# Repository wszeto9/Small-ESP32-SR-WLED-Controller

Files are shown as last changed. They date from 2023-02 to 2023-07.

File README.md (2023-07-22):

# Small ESP32 SR-WLED Controller

A small LED controller that runs WLED-Sound Reactive. Supports 5-24V analog and addressible lights.

[Interactive BOM](https://htmlpreview.github.io/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)

<h2> Features:</h2>
<ul>
<li>4 Analog Channels (Up to 3A each) for analog RGB and RGBW LED strips</li>
<li>2 Addressible Channels, level shifted to 5V to support single data line and dual data line addressible LED strips.
<li>Variable Input voltage from 5-24V (Input voltage must match the LED strip voltage)
<li>Controlled with an ESP8266 running WLED and connected over Wi-Fi</li>
<li>Panelized in a 2x2 panel of 50x50mm for minimal fabrication costs at JLCPCB</li>
<li>BOM cost is kept low at around $6 per board
</ul>
<h2>Pinout</h2>

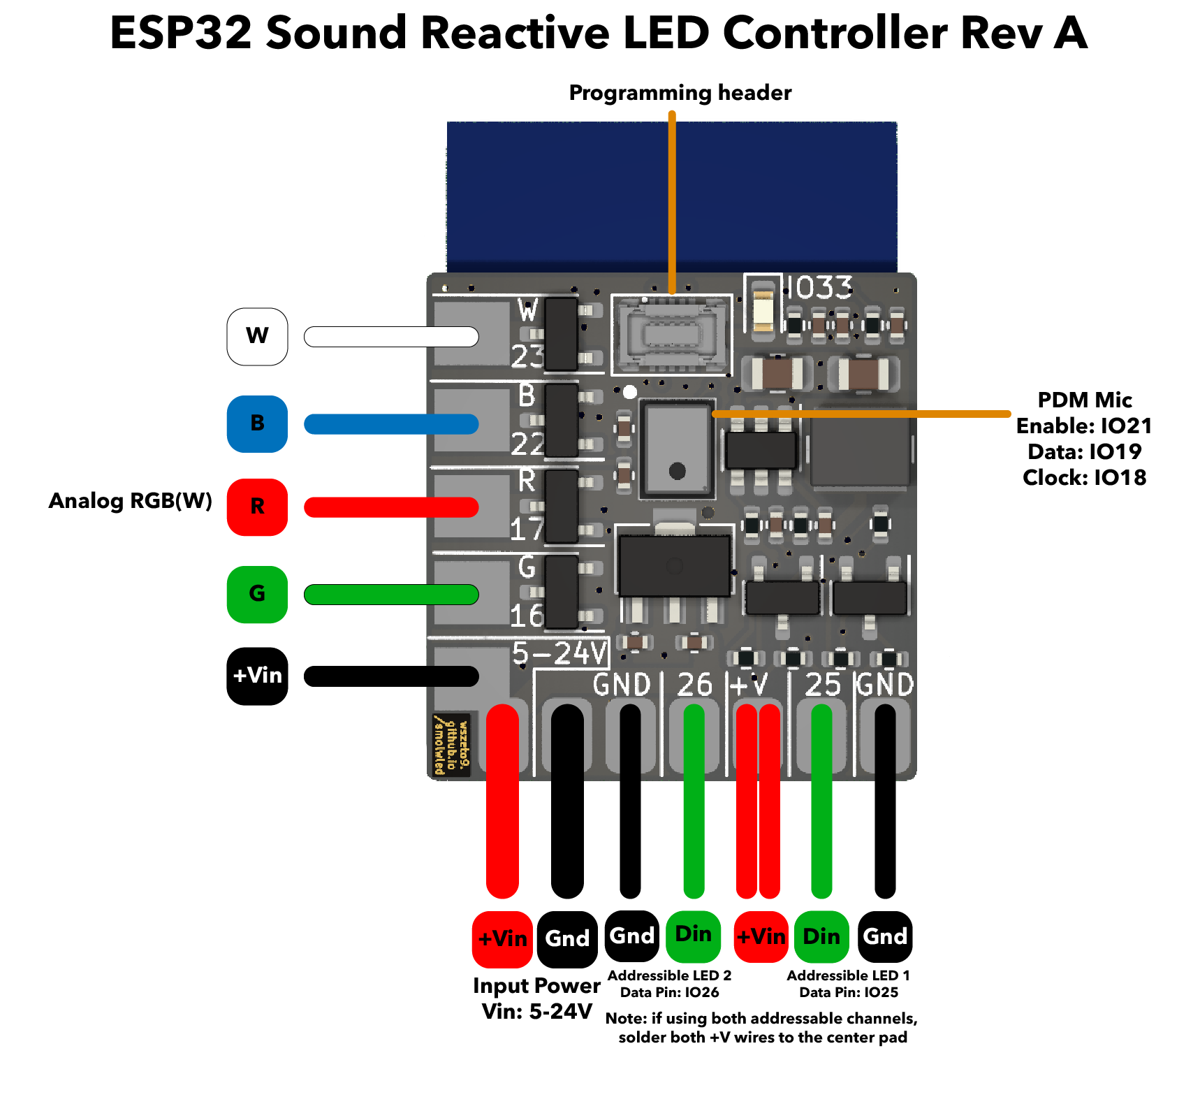
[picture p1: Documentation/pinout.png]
Pinout

<h2> Bring-up and Usage </h2>

- All front components should be soldered by JLCPCB.
- Flip the board and solder the ESP32 WROOM chip.
- Attach the programming device onto the mezzamine connector on the top front of the board
- Program the ESP32 with WLED
- Unplug the programming header
- Solder on lights and a power lead
- Connect to the ESP's Wi-Fi network and turn on the lights!

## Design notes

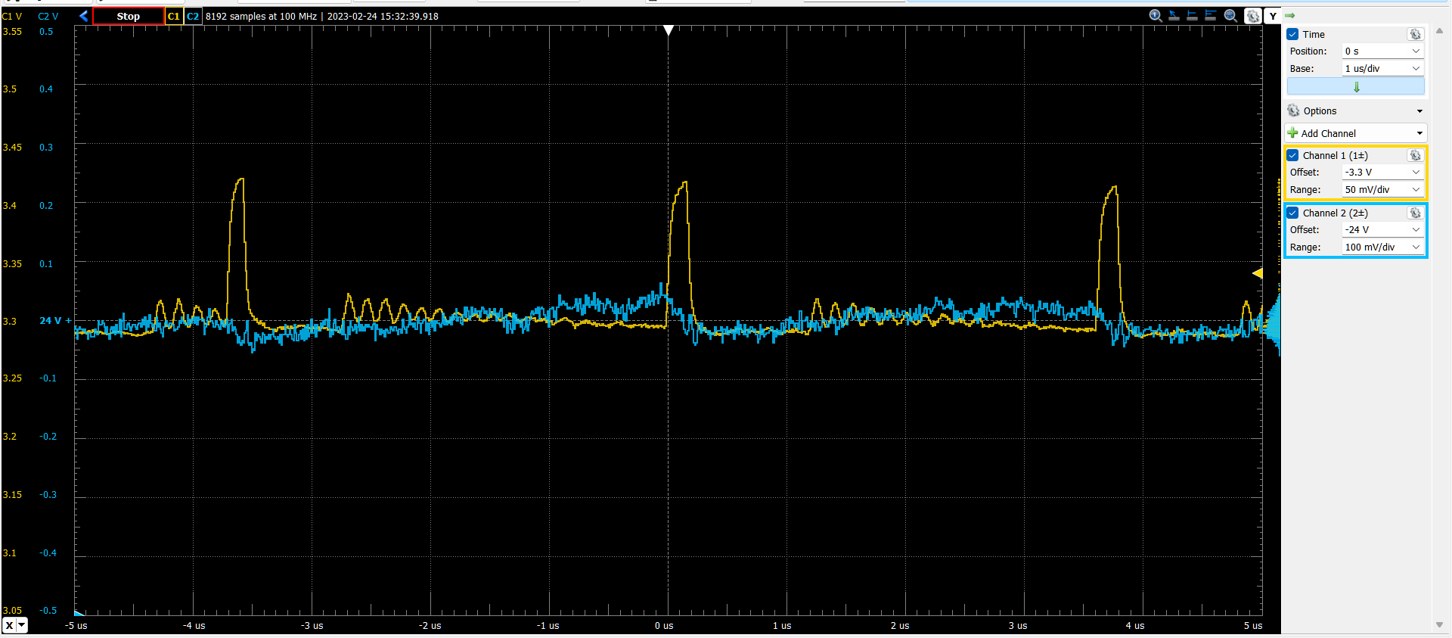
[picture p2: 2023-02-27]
Documentation/3V3ripple_24Vin.png

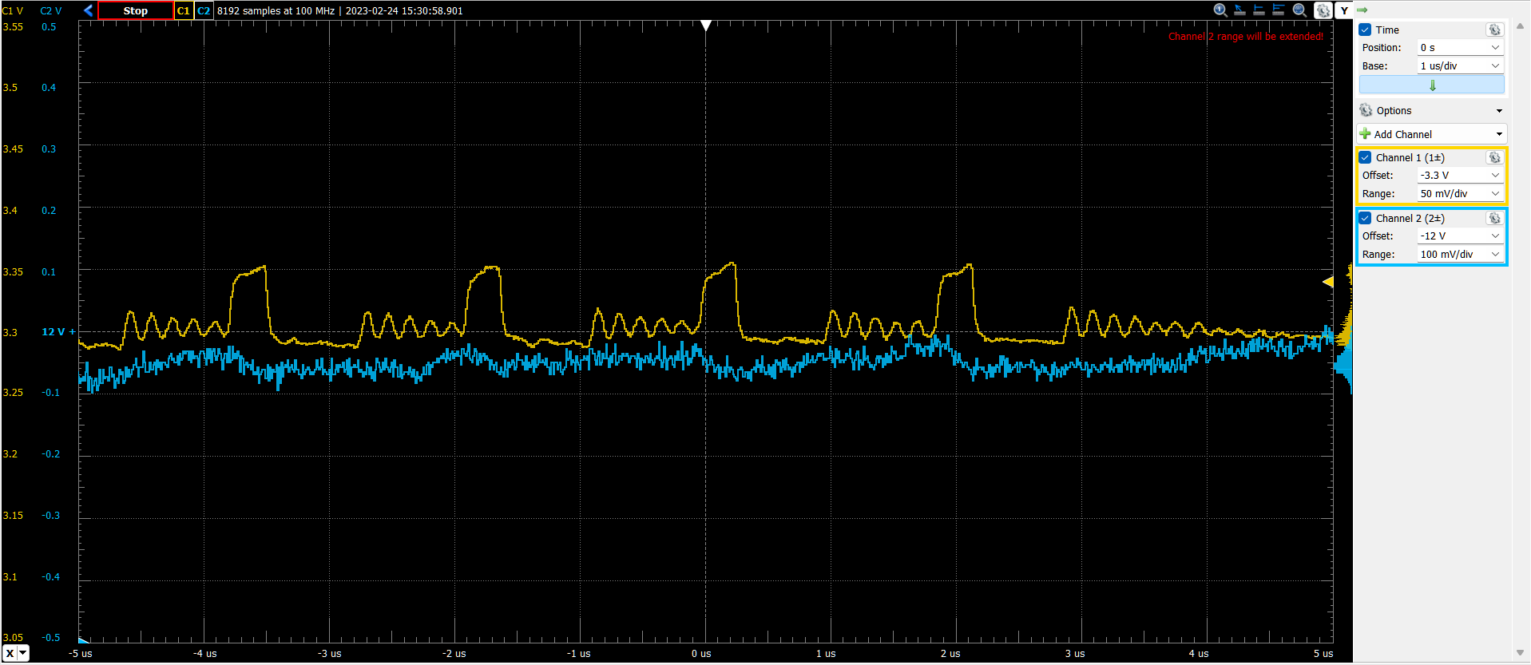
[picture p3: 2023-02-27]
Documentation/3V3ripple_12Vin.png

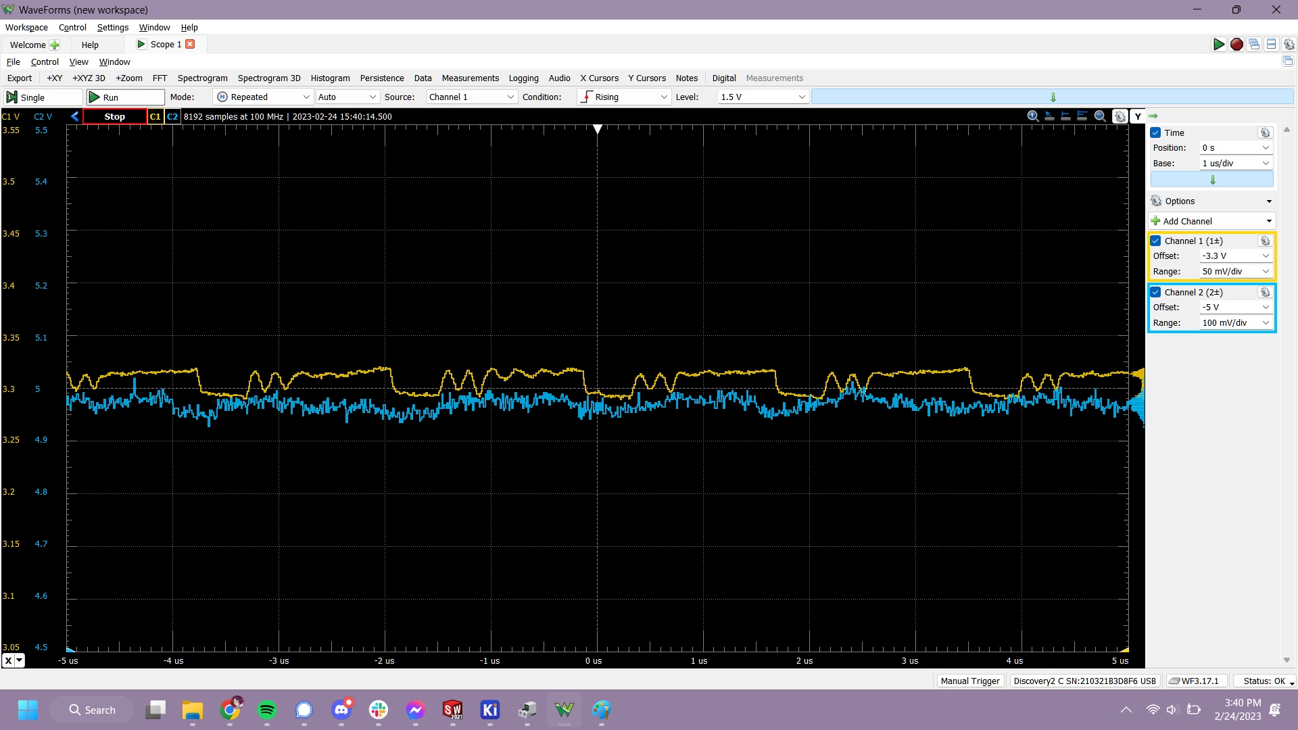
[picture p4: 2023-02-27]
Documentation/3V3ripple_5Vin.png

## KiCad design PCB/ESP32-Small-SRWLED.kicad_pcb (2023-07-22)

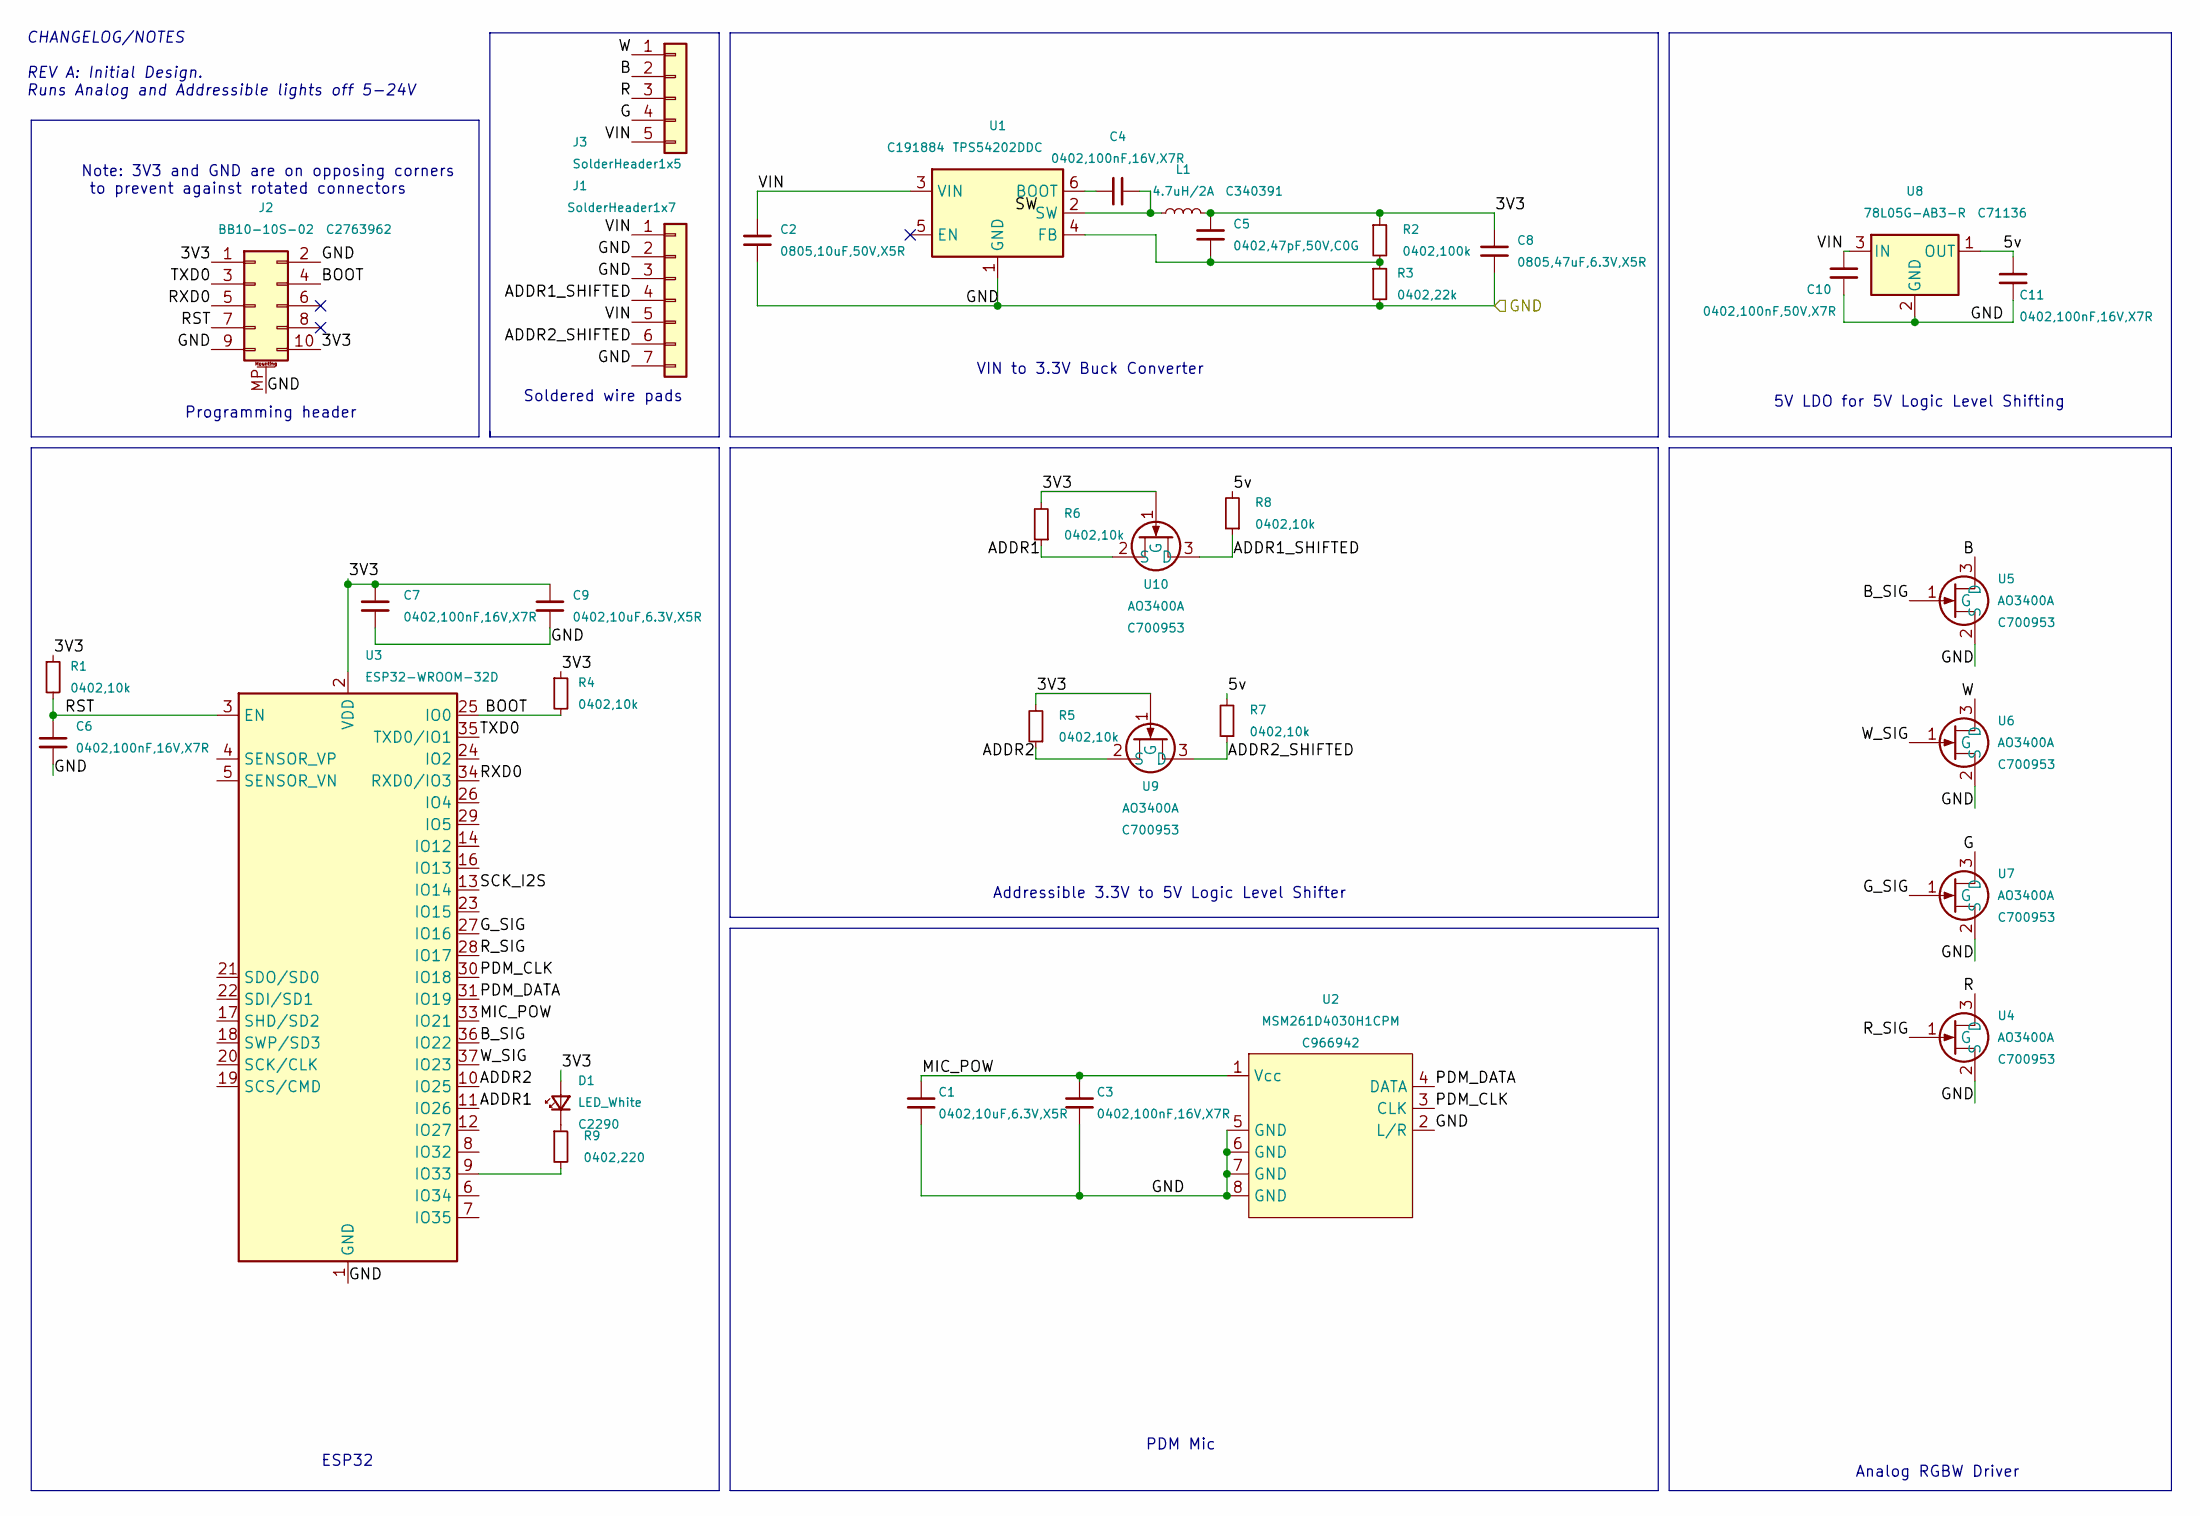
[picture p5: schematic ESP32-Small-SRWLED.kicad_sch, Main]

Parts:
C1, C9: 0402,10uF,6.3V,X5R; C_0402_1005Metric; MFGPN CL05A106MQ5NUNC; LCSC C15525
C2: 0805,10uF,50V,X5R; C_0805_2012Metric; MFGPN GRM21BR61H106KE43L; LCSC C440198
C3, C4, C6, C7, C11: 0402,100nF,16V,X7R; C_0402_1005Metric; MFGPN CL05B104KO5NNNC; LCSC C1525
C5: 0402,47pF,50V,C0G; C_0402_1005Metric; MFGPN 0402CG470J500NT; LCSC C1567
C8: 0805,47uF,6.3V,X5R; C_0805_2012Metric; MFGPN CL21A476MQYNNNE; LCSC C16780
C10: 0402,100nF,50V,X7R; C_0402_1005Metric; MFGPN CL05B104KB54PNC; LCSC C307331
D1: LED_White; LED_0603_1608Metric; LCSC C2290
J1: SolderHeader1x7; 1x7 wire solder pad
J2: BB10-10S-02; YXT-BB10-10S-02; LCSC C2763962
J3: SolderHeader1x5; 1x5 solder pad
L1: 4.7uH/2A; L_Wuerth_MAPI-4030; MFGPN YNR4030-4R7M; LCSC C340391
R1, R4, R5, R6, R7, R8: 0402,10k; R_0402_1005Metric; MFGPN 0402WGF1002TCE; LCSC C25744
R2: 0402,100k; R_0402_1005Metric; MFGPN 0402WGF1003TCE; LCSC C25741
R3: 0402,22k; R_0402_1005Metric; MFGPN 0402WGF2202TCE; LCSC C25768
R9: 0402,220; R_0402_1005Metric; MFGPN 0402WGF2200TCE; LCSC C25091
U1: TPS54202DDC; SOT-23-6; MFGPN TPS54202DDCR; LCSC C191884
U2: MSM261D4030H1CPM; LCSC C966942
U3: ESP32-WROOM-32D; ESP32-WROOM-32; LCSC C473005
U4, U5, U6, U7, U9, U10: AO3400A; SOT-23; LCSC C700953
U8: 78L05G-AB3-R; SOT-89-3; LCSC C71136

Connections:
/3V3: C5.1, C7.1, C8.1, C9.1, D1.2 (A), J2.1, J2.10, L1.2, R1.1, R2.1, R4.1, R5.2, R6.2, U3.2 (VDD), U9.1 (G), U10.1 (G)
/5v: C11.1, R7.2, R8.2, U8.1 (OUT)
/ADDR1: R6.1, U3.11 (IO26), U10.2 (S)
/ADDR1_SHIFTED: J1.4, R8.1, U10.3 (D)
/ADDR2: R5.1, U3.10 (IO25), U9.2 (S)
/ADDR2_SHIFTED: J1.6, R7.1, U9.3 (D)
/B: J3.2, U5.3 (D)
/BOOT: J2.4, R4.2, U3.25 (IO0)
/B_SIG: U3.36 (IO22), U5.1 (G)
/G: J3.4, U7.3 (D)
/GND: C1.2, C2.2, C3.2, C6.2, C7.2, C8.2, C9.2, C10.2, C11.2, J1.2, J1.3, J1.7, J2.2, J2.9, J2.MP (MountPin), R3.2, U1.1 (GND), U2.2 (L/R), U2.5 (GND), U2.6 (GND), U2.7 (GND), U2.8 (GND), U3.1 (GND), U3.15 (GND), U3.38 (GND), U3.39 (GND), U4.2 (S), U5.2 (S), U6.2 (S), U7.2 (S), U8.2 (GND)
/G_SIG: U3.27 (IO16), U7.1 (G)
/MIC_POW: C1.1, C3.1, U2.1 (Vcc), U3.33 (IO21)
/PDM_CLK: U2.3 (CLK), U3.30 (IO18)
/PDM_DATA: U2.4 (DATA), U3.31 (IO19)
/R: J3.3, U4.3 (D)
/RST: C6.1, J2.7, R1.2, U3.3 (EN)
/RXD0: J2.5, U3.34 (RXD0/IO3)
/R_SIG: U3.28 (IO17), U4.1 (G)
/SCK_I2S: U3.13 (IO14)
/TXD0: J2.3, U3.35 (TXD0/IO1)
/VIN: C2.1, C10.1, J1.1, J1.5, J3.5, U1.3 (VIN), U8.3 (IN)
/W: J3.1, U6.3 (D)
/W_SIG: U3.37 (IO23), U6.1 (G)
unnamed: C4.1, U1.6 (BOOT)
unnamed: C4.2, L1.1, U1.2 (SW)
unnamed: C5.2, R2.2, R3.1, U1.4 (FB)
unnamed: D1.1 (K), R9.1
unnamed: R9.2, U3.9 (IO33)

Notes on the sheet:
5V LDO for 5V Logic Level Shifting
VIN to 3.3V Buck Converter
PDM Mic
Analog RGBW Driver
Programming header
Addressible 3.3V to 5V Logic Level Shifter
Soldered wire pads
ESP32
Note: 3V3 and GND are on opposing corners to prevent against rotated connectors
CHANGELOG/NOTES REV A: Initial Design. Runs Analog and Addressible lights off 5-24V

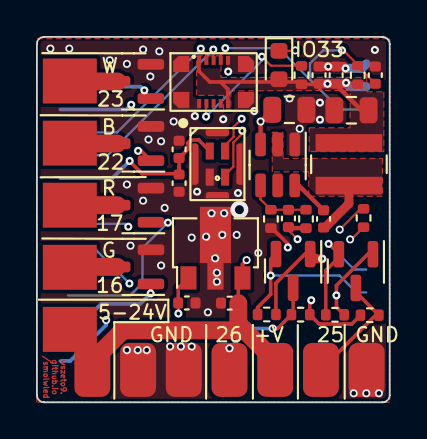
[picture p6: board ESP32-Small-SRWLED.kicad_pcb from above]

Board: 4 copper layers, 19.6 x 20.3 mm, 35 parts (1 on the bottom side), 28 nets.

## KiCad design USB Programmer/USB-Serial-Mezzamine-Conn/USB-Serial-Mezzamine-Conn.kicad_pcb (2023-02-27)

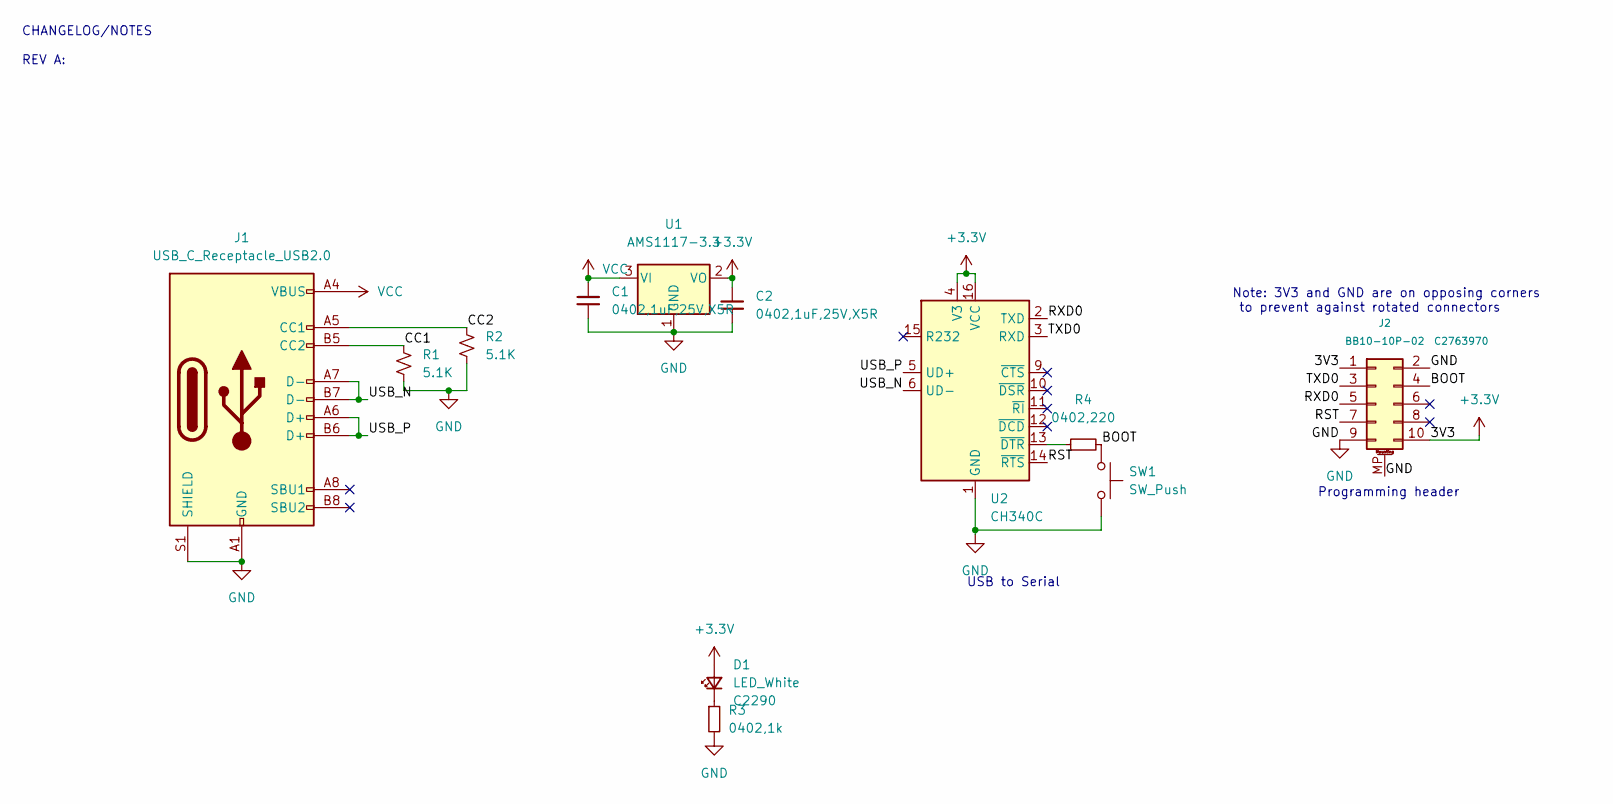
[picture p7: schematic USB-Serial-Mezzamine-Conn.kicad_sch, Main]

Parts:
C1, C2: 0402,1uF,25V,X5R; C_0402_1005Metric; MFGPN CL05A105KA5NQNC; LCSC C52923
D1: LED_White; LED_0603_1608Metric; LCSC C2290
J1: USB_C_Receptacle_USB2.0; USB_C_Receptacle_Palconn_UTC16-G; LCSC Part Number C165948
J2: BB10-10P-02; YXT-BB10-10P-02; LCSC C2763970
R1, R2: 5.1K; R_0402_1005Metric; LCSC Part Number C25905
R3: 0402,1k; R_0402_1005Metric; MFGPN 0402WGF1001TCE; LCSC C11702
R4: 0402,220; R_0402_1005Metric; MFGPN 0402WGF2200TCE; LCSC C25091
SW1: SW_Push; SW_PUSH_6mm
U1: AMS1117-3.3; SOT-223-3_TabPin2
U2: CH340C; SOIC-16_3.9x9.9mm_P1.27mm; LCSC Part Number C84681

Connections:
+3V3: C2.1, D1.2 (A), J2.1, J2.10, U1.2 (VO), U2.4 (V3), U2.16 (VCC)
/BOOT: J2.4, R4.2, SW1.1
/CC1: J1.B5 (CC2), R1.1
/CC2: J1.A5 (CC1), R2.1
/RST: J2.7, U2.14 (~RTS)
/RXD0: J2.5, U2.2 (TXD)
/TXD0: J2.3, U2.3 (RXD)
/USB_N: J1.A7 (D-), J1.B7 (D-), U2.6 (UD-)
/USB_P: J1.A6 (D+), J1.B6 (D+), U2.5 (UD+)
GND: C1.2, C2.2, J1.A1 (GND), J1.A12 (GND), J1.B1 (GND), J1.B12 (GND), J1.S1 (SHIELD), J2.2, J2.9, J2.MP (MountPin), R1.2, R2.2, R3.2, SW1.2, U1.1 (GND), U2.1 (GND)
unnamed: D1.1 (K), R3.1
unnamed: R4.1, U2.13 (~DTR)
VCC: C1.1, J1.A4 (VBUS), J1.A9 (VBUS), J1.B4 (VBUS), J1.B9 (VBUS), U1.3 (VI)

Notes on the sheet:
Programming header
Note: 3V3 and GND are on opposing corners to prevent against rotated connectors
USB to Serial
CHANGELOG/NOTES REV A:

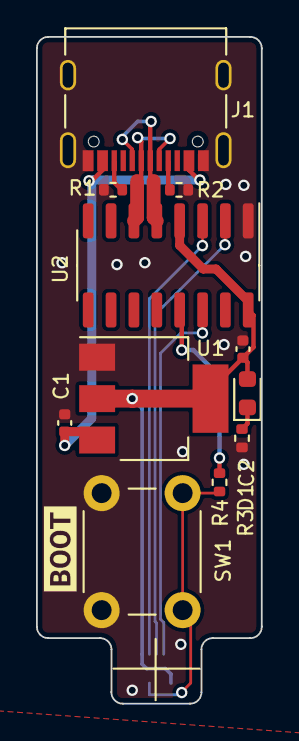
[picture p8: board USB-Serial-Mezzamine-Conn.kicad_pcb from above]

Board: 2 copper layers, 12.5 x 37.0 mm, 13 parts (1 on the bottom side), 13 nets.

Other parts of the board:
kibuzzard-63EDCBFB: G***; kibuzzard-63EDCBFB

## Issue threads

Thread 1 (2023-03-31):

Addressable LED Signal Integrity Issues

wszeto9, 2023-03-31:
While WS2812Bs were able to be controlled with the controller, the control signals have some SI issues. In summary, Rev A02 should include the following changes:
|Reference|Rev A01 Part|Rev A02 Part|
|--|--|--|
|U8|78L05G-AB3-R|AP2205-50YR-13‎|
|U9| AO3400A|BSS138|
|U10 | AO3400A|BSS138|
R7|10K 0402|1K 0402|
R9|10K 0402|1K 0402|

- The 5V Logic Voltage Regulator has a high dropout voltage of roughly 1.5V. This means, with a 5V VIN on the controller, the logic "5V" rail is only at 3.5V. A suggested replacement part for U8 is ‎AP2205-50YR-13‎. The part is pin-compatible and has a low dropout of ~ 100mV.
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
Figure 1:
Output Voltage (Vertical) vs Input Voltage (Horizontal) of U8 in Rev A01. Bottom left corner represents 0V on input and 0V on output. With 5V input, the output is approximately 3.8V. A 6.5V input voltage is required to sustain a 5V output voltage.
- The AO3400A has excess stray capacitance. It significantly loads the signal input such that the input signal takes roughly 100ns to rise to 3.3V. In addition, the AO3400A has a relatively high threshold voltage, leading to the mosfet taking too long to switch. The high-time of the output signal is at roughly 0.1us, which is not long enough to sufficiently control the WS2812B. It is recommended to use the BSS138 as a replacement for U9 and U10. The BSS138 is used in figure 3.
- 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
Figure 2: The affect of the AO3400A on the input signal. Logic Voltage (Yellow), microcontroller signal (Blue), Output signal(Red). The AO3400A significantly softens the signal. The point the mosfet turns off can be seen when the blue trace drops. The output signal does not reach a 3.5V threshold until 0.3us after the microcontroller signal first goes high.
- The pullups R7,R8 are not strong enough to pull up the output signal in a short period of time. They should be replaced with a 1K 0402 in order to drain parasitic capacitances quicker.
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
Figure 3: Effect of different pull-up values on switching transient. Logic Voltage (Yellow), microcontroller signal (blue), Output signal with 1K pullup (Red), Output signal with 10K pullup(Green). Since the weaker pullup takes longer to pull the signal high, the high-time of the signal is changed. U9 and U10 are using the BSS138.

For a logic 0 to be transmitted, the high pulse time must be between 0.25us and 0.55us. High pulse time is defined as the time at which a signal is above 3.5V (VIH) for the output signals, and is estimated to be 0.4us for the input.
|Signal| High pulse time|
|--|--|
|Input|0.4us|
|Output with 10K Pullup | 0.266us|
|Output with 1K Pullup | 0.378us|

The 1K pullup is significantly more resilient than the 10K pullup. With the 10K pullup, its high pulse time is very close to the acceptable  lower limit. The 1K pullup provides a much higher safety margin and is therefore a better choice as a pullup resistor value.

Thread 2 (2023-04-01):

Incorrect silkscreen

wszeto9, 2023-04-01:
The silkscreen is incorrect. ADDR1 and ADDR2 are swapped, and R and G should have a GPIO number that is one less than depicted on the silkscreen. The pinout should be as follows:

|Function | Pin Number|
|-|-|
|G | 16|
|R|17|
|B|22|
|W|23|
|ADDR1|26|
|ADDR2|25|

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
Figure 1: Silkcreen on Rev A
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

FIgure 2: Corrected Silkscreen

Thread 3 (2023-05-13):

nRST rising too quickly before BOOT is set correctly

wszeto9, 2023-05-13:
The nRST line on the ESP32 is switching to H approximately 1.5ms before the 3V3 voltage rail is stable, as shown in Fig. 1. This is undesirable, as the ESP32 may be unstable and go into an incorrect boot mode due to this. Some boards did not have a functional ESP32 due to the IC not turning on properly. To fix this issue, a 1uF capacitor is placed between nRST and GND (replacing the 100nF capacitor C6), resulting in the ESP32 reading nRST high approximately 8ms after 3V3 is stable, as shown in Fig 2.  The ESP32 was able to turn on properly after the fix.

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
**Figure 1:** A transient analysis of the circuit turning on. The blue curve is VIN, the cyan curve is 3V3, yellow is nRST, and purple is 0.75 * 3V3, which is the high threshold for the ESP32. The ESP32 gets an enable signal at -0.5ms, whereas 3V3 stabilizes at +1ms. The ESP32 is being told to turn on before the voltage rails are stable.

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
**Figure 2:** A transient analysis of the circuit turning on with a 1uF capacitor between nRST and GND. The blue curve is VIN, the yellow curve is 3V3, cyan is nRST, and purple is 0.75 * 3V3, which is the high threshold for the ESP32. Cursor AX shows when 3V3 is stable, and cursor BX shows when the ESP32 is enabled. The ESP32 is turned on approximately 8ms after the voltage rail is stabilized.

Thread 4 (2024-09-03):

Adding a capacitive touch sensor input

Arakistech, 2024-09-03:
Hi! Great work, your design is very nice.

I would like to add a capactive touch sensor input to it to switch the LEDs on/off with WLED. I would use the capacitive touch sensor through some milimeters of wood.  Do you know how can I do it?

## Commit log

2023-02-14 Routed components
    [ESP32-Small-SRWLED.kicad_pcb, ESP32-Small-SRWLED.kicad_sch]
2023-02-14 edited website link
    [ESP32-Small-SRWLED.kicad_pcb, ESP32-Small-SRWLED.kicad_sch]
2023-02-14 changed file dir
    [ESP32-Small-SRWLED.kicad_pcb, ESP32-Small-SRWLED.kicad_sch]
2023-02-27 sent to fab
    [ESP32-Small-SRWLED.kicad_pcb, ESP32-Small-SRWLED.kicad_sch, ESP32-Small-SRWLED_panelization.kicad_pcb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]
2023-02-27 Added scope shots of 3.3V ripple voltage
2023-04-01 moved bom and step to documentation
2023-07-22 Adding documentation
    [ESP32-Small-SRWLED.kicad_pcb]
